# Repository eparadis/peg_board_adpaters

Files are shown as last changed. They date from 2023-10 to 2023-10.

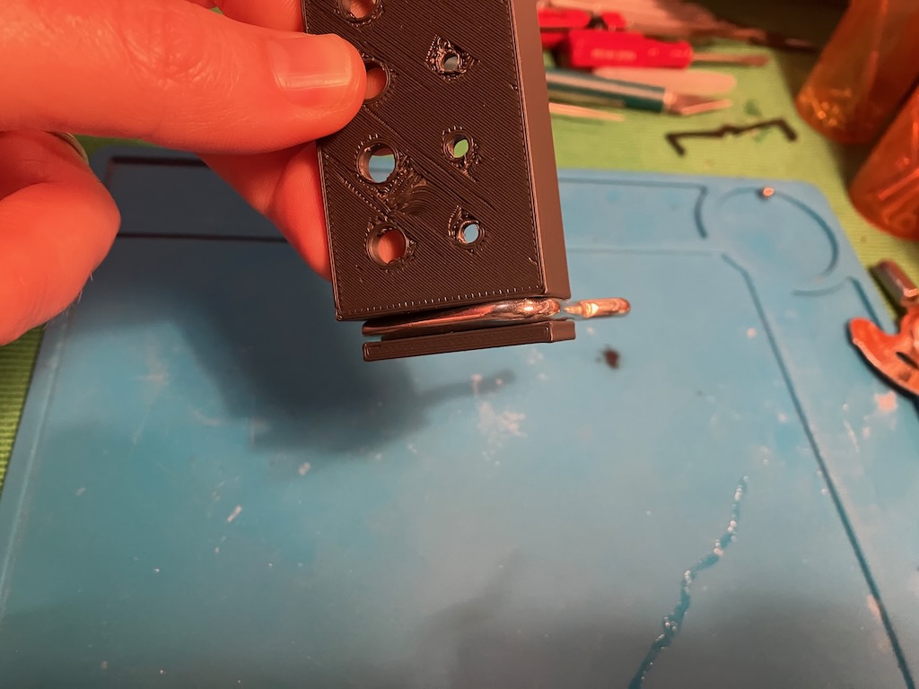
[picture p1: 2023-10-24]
images/IMG_2507.jpeg

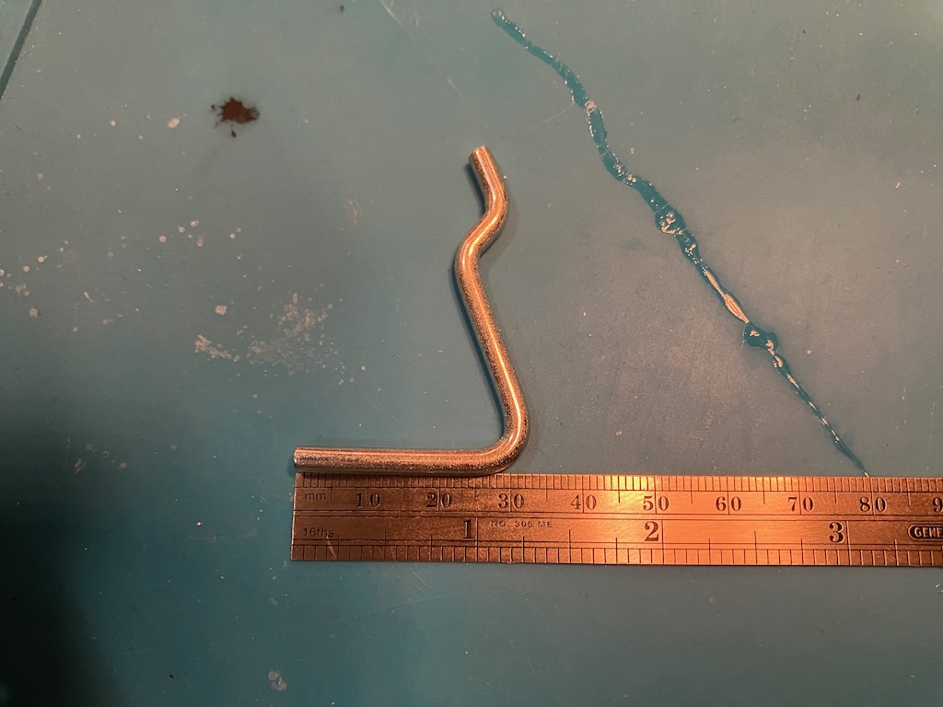
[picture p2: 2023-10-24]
images/IMG_2508.jpeg

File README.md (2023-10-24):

Instead of buying a whole new tool pegboard system, just re-use the junky hooks to make secure holders for your tools!

This is a small shelf that securely hangs on the inexpensive hooks available from Harbor Freight. I designed it to fit small tools like allen wrenches or small screwdrivers, but it is widely customizable to fit various needs.

# Customization Parameters

## `size_in_pegs`

The width of shelf in the number of peg holes it takes up.

## `depth`

The distance (in mm) that the shelf extends from the peg board. It includes the strengthening piece across the back that lays against the peg board.

## `hole_diameter`

The diameter (in mm) of the first row of holes.

## `holes_per_peg`

The number of holes in the shelf included in the distance between two peg holes. Holes start a bit away from the edge of the shelf. For example, a with `size_in_pegs=3` and `holes_per_peg=2`, you end up with five holes in a row.

## `two_rows`

Set to true to get two rows of holes spaced apart. Set to false to get one row centered in the shelf.

## `second_row_diameter`

The same as `hole_diameter` but for the second row of holes.

## `height`

The overall height of the shelf. Increase this to make the shelf “taller” which can help stability for larger tools by putting the center of gravity lower.

## `shelf_thickness`

The thickness of the shelf itself. Increase this to provide more support for your tools if they tend to flop over.

# Printing

You can print this in any orientation that makes sense to you for where you want the strength to be. You'll need to use supports most likely no matter what, but you won't need much.

I printed my shelves on a Prusa MINI with Hatchbox Dark Gray Matte PLA using the “0.25mm DRAFT” preset with “supports on build plate only” with the model oriented upright (the way it will be used on the peg board).

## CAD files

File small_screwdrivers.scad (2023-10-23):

// holds small screwdrivers, tip down
// uses cheap pegboard hooks

include <BOSL2/std.scad>

size_in_pegs = 3;
depth = 34;
hole_diameter = 3.1;
holes_per_peg = 2;
two_rows = true;
second_row_diameter = 5.5;
height = 20;
shelf_thickness = 3;

module _stop_customizer() {}

// the screw drivers I want to hang with this have the following diameters:
// 4.32, 1.42, 1.97, 3.11, 2.36, 2.95, 3.80


$fn = 32;

function peg_board_holes_to_mm(x) = INCH * x;

module hook_rest() {
  angle = 70.1;
  dist_from_board = 4;
  T=3.8;
  H=height;
  g = 30;
  x = depth-dist_from_board > g-dist_from_board ? g-dist_from_board : depth-dist_from_board;
  tcmds = [
    "right",90, "move",H-8, "arcleft",4.5,180-angle, "untilx",x,
    "left",angle, "untily", 0
  ];
  path = turtle(tcmds);
  translate([dist_from_board,0,-T/2]) linear_extrude(height=T, convexity=10) polygon(path);

  // outside support
  translate([0,-H,T/2]) cube([x+dist_from_board,H,3]);

  // inside support
  radius = min( H-3, depth-(x+dist_from_board));
  translate([0,0,-T/2-3]) linear_extrude(height=3) polygon(turtle([
    "move",depth-radius, "arcright",radius,90, "untily",-H,
    "right",90, "untilx",0,
  ]));
}

module shelf(D, W, T) {
  cube([D, W-5, T]);
  cube([3,W-5,height]);
}

module holes(W, dia) {
  for (i=[0:peg_board_holes_to_mm(1/holes_per_peg):W-25]) {
    translate([0, i+10, -10]) cylinder(h=height*2, d=dia);
  }
  echo(str("hole spacing is: ", peg_board_holes_to_mm(1/holes_per_peg)));
}

module shelf_with_holes(W) {
  D = depth;
  difference() {
    shelf(D, W, shelf_thickness);
    if(two_rows) {
      translate([3+(depth-3)*.25,0,0]) holes(W, hole_diameter);
      translate([3+(depth-3)*.67,0,0]) holes(W, second_row_diameter);
      echo(str("distance between rows (center to center): ", (depth-3)*.67 - (depth-3)*.25));
    } else {
      translate([3+depth/2,0,0]) holes(W, hole_diameter);
    }
  }
}

module screwdriver_holder(hook_distance) {
  W = hook_distance;
  D = depth;
  rotate([90,0,0]) hook_rest();
  mirror([0,1,0]) translate([0,-W,0]) rotate([90,0,0]) hook_rest();
  
  translate([0,2.5,-height]) shelf_with_holes(W);
}

//shelf_with_holes(peg_board_holes_to_mm(size_in_pegs));
screwdriver_holder(peg_board_holes_to_mm(size_in_pegs));

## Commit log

2023-10-23 basic shape to rest on one of the cheap hooks. needs measurement
    [small_screwdrivers.scad]
2023-10-23 refine hook rest. add shelf
    [small_screwdrivers.scad]
2023-10-23 refactor and make parametric
    [small_screwdrivers.scad]
2023-10-23 more parameters
    [small_screwdrivers - my print.3mf, small_screwdrivers.3mf, small_screwdrivers.scad]
2023-10-23 add optional double row of holes
    [small_screwdrivers.scad]
2023-10-23 radius the inside support to match any depth shelf
    [small_screwdrivers.scad]
2023-10-23 correct for measurements of actual hook
    [small_screwdrivers - my print.3mf, small_screwdrivers.scad]
2023-10-23 allow for differently sized holes for the two rows. values from measurements
    [small_screwdrivers.scad]
2023-10-23 remove rendered files
    [small_screwdrivers - my print.3mf, small_screwdrivers.3mf]
2023-10-23 add height as parameter and tune to actual hook
    [small_screwdrivers.scad]
2023-10-23 hook thickness from measurement
    [small_screwdrivers.scad]
2023-10-23 add the doc I wrote for Printables
2023-10-23 make shelf thickness a parameter
    [small_screwdrivers.scad]
2023-10-24 add images of success print
